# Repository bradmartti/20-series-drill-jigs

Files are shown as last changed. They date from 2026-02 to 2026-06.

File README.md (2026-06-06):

[][cc-by-nc-sa]

This work is licensed under a  
[Creative Commons Attribution-NonCommercial-ShareAlike 4.0 International License][cc-by-nc-sa].

[][cc-by-nc-sa]

[cc-by-nc-sa]: http://creativecommons.org/licenses/by-nc-sa/4.0/
[cc-by-nc-sa-image]: https://licensebuttons.net/l/by-nc-sa/4.0/88x31.png
[cc-by-nc-sa-shield]: https://img.shields.io/badge/License-CC%20BY--NC--SA%204.0-lightgrey.svg

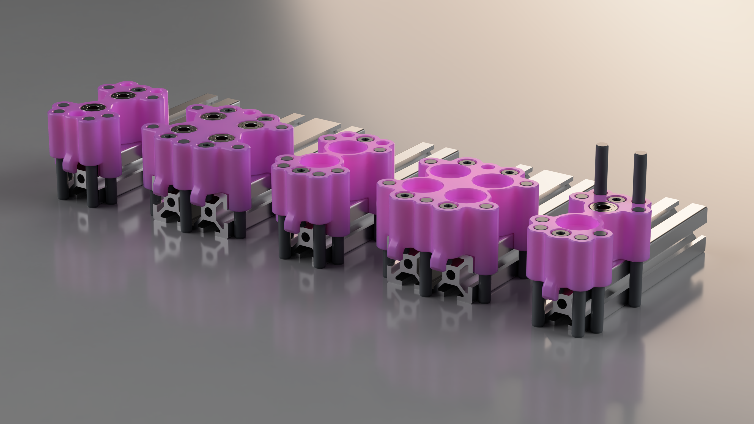
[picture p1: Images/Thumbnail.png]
Thumbnail


## Introduction

These jigs enable precise drilling of 20-series aluminum extrusions for through-hole counterbored joints and access-hole blind joints.

### Features
- Double bearing guides with tight tolerances provide excellent drill bit support for precise, clean holes
- Multi-point T-nut clamping for secure fixture connection
- T-nut anti-spin design prevents T-nuts from rotating, enabling quick and easy installation
- Optional side alignment pins for improved alignment and jig longevity
- End alignment pins for common fixed-offset drilling
- Convenient alignment locations for matching to measured marks on the extrusion
- Designed for Additive Manufacturing (DfAM)
- Optional multi-purpose jig that handles various extrusion sizes and joint types — ideal for non-repetitive or mixed jobs where setup/removal time is acceptable in exchange for fewer dedicated tools

## Hardware

| Item | Recommended Source |
|---|---|
| 685ZZ 5×11×5 mm bearing | [Aliexpress](https://www.aliexpress.com/item/1005006224445582.html) |
| R1038ZZ 3/8" × 5/8" × 5/32" bearing | [Amazon.ca](https://www.amazon.ca/HiPicco-R1038ZZ-Bearings-Miniature-Shielded/dp/B0CH37GYYF?th=1), [Amazon.com](https://www.amazon.com/FOCMKEAS-R1038ZZ-Industrial-Mechanical-Equipment/dp/B0B6WRXGZR) |
| 5 mm × 40 mm pin (or custom length) | [Aliexpress](https://www.aliexpress.com/item/4000473863693.html)|
| 5 mm drill bit | [Aliexpress - XUHAN](https://www.aliexpress.com/item/1005002617939096.html) |
| 5.5–9.5 mm step drill | [Aliexpress - DrillForce](https://www.aliexpress.com/item/32914005099.html#nav-specification) |
| 5 mm and 9.5 mm depth stop collars | [Aliexpress](https://www.aliexpress.com/item/1005005826023888.html) |
| M4 T-nut (9.5 mm length) | [Aliexpress](https://www.aliexpress.com/item/1005007883028035.html) |
| M4 × 20 mm SHCS screw | [Aliexpress](https://www.aliexpress.com/item/1005004527586307.html) |

## Important Notes
- Check the CAD files for exact quantities required per jig variant.
- Drill bits have very tight clearance with the bearings — lubricant is highly recommended for smooth motion and better cutting performance.
- **Use higher spindle RPM with a slower/controlled feed rate** to achieve a lower chip load — this prevents drill bit binding, and produces cleaner holes (apply very light pressure when hand-feeding).
- Pin holes should be drilled/reamed to 5 mm; apply light grease or lubricant so pins slide easily but do not fall out.
- Side alignment pins are optional for most variants (required for the multi-jig version); front/end alignment pins provide a fixed offset.
- Counterbore overhangs are intentionally bridged to simplify printing — insert bearings first, then drill out.
- If printed tolerances do not match your needs (e.g., too tight/loose), adjust them using the included Fusion 360 parameter file — use care for other changes, as major modifications may break the model.
- If bearings don't stay in place, adjust tolerances in CAD and/or use retaining compound to secure them.
- The 9.5 mm T-nut length is required for the anti-spin feature to function correctly (length can be adjusted in the CAD if needed).
- **When drilling 4040 extrusions for through-hole counterbored joints, pre-drill with the blind-hole jig to make the counterbore drilling easier and to account for the counterbore bit not reaching the full depth of the extrusion.**

<div style="display: flex; gap: 1%; justify-content: space-around;">
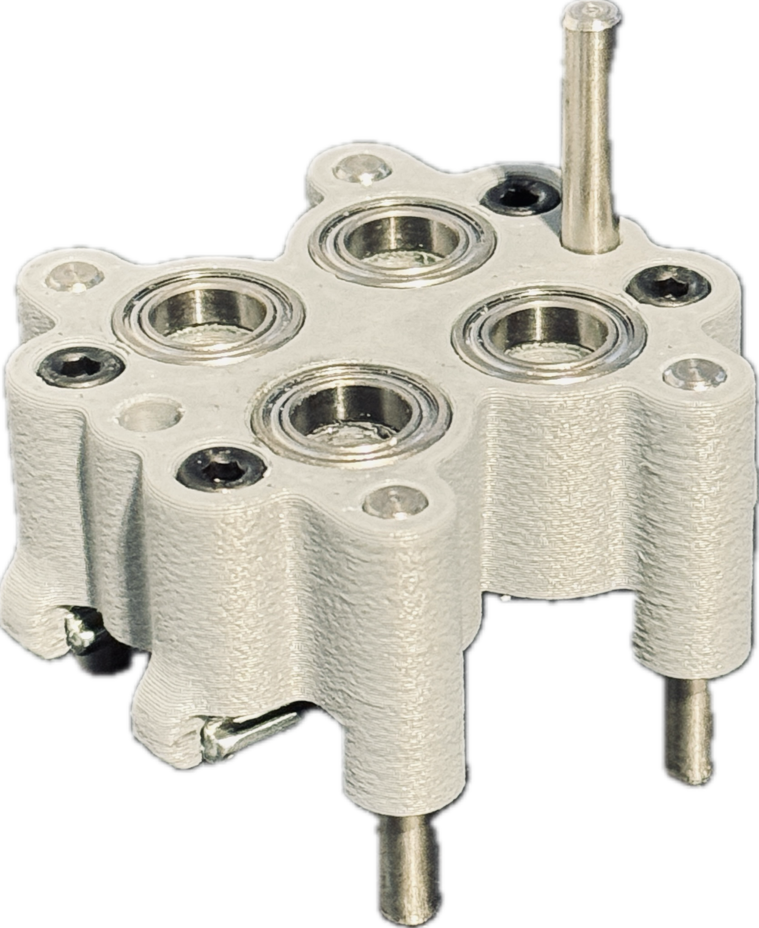
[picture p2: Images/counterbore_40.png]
  
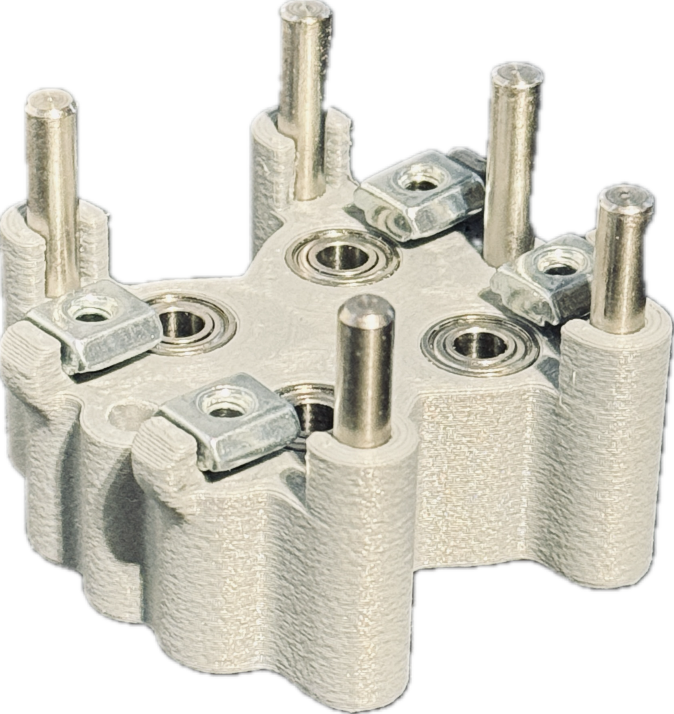
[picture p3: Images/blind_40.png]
  
</div>

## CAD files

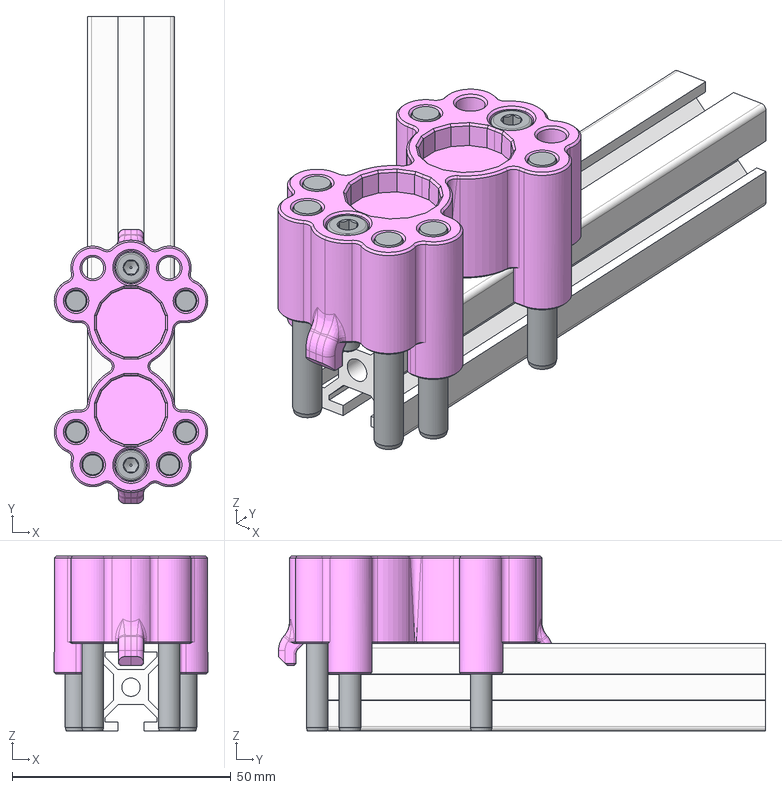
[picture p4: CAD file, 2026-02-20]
CAD/STEP/Counterbore_20.step
35.1 x 111.4 x 40.0 mm

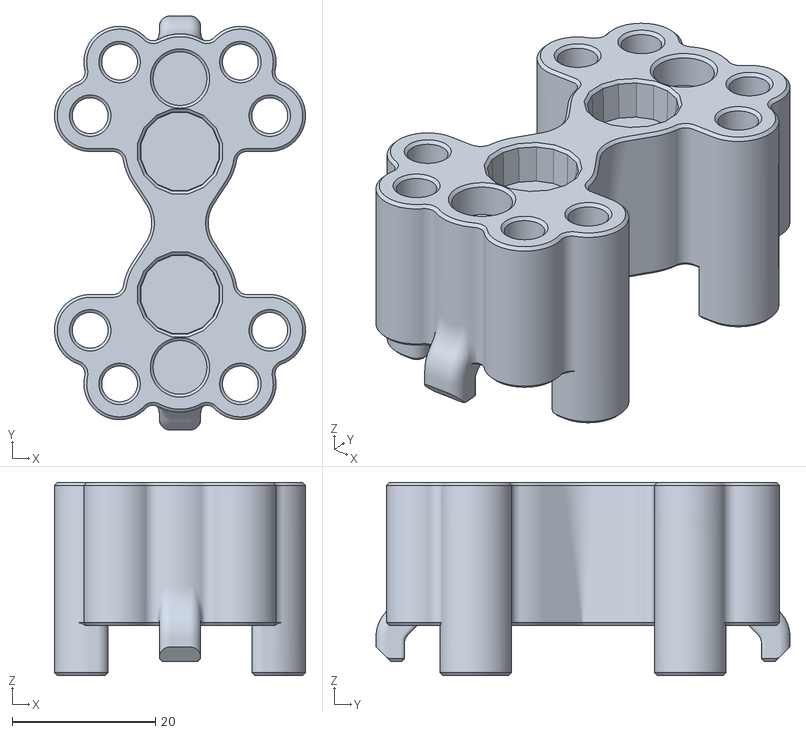
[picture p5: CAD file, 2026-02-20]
files_for_printing/Blind_20.stl
35.1 x 57.9 x 27.0

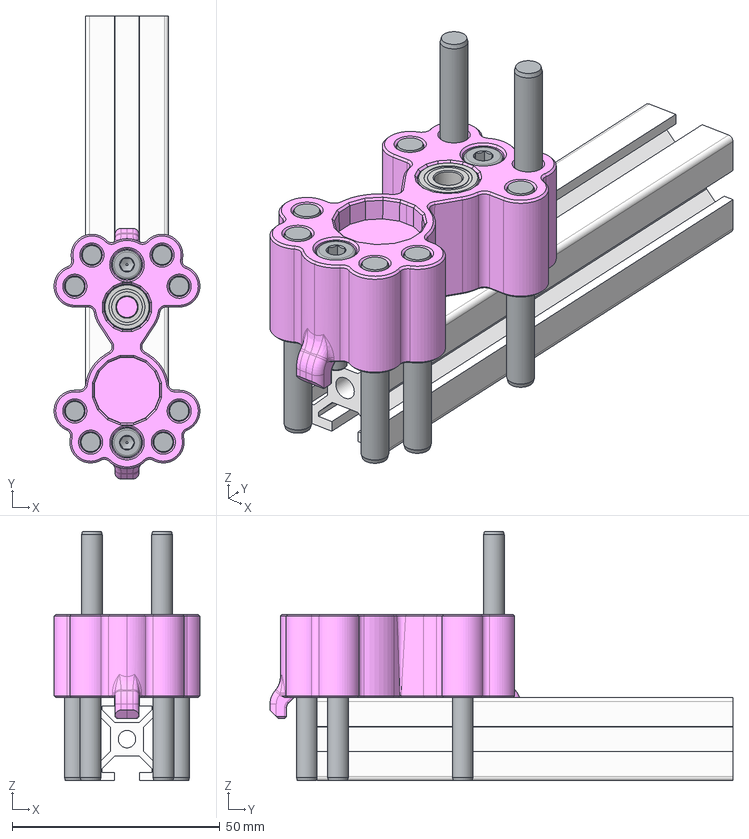
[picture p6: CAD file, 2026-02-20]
CAD/STEP/Multi_20.step
35.1 x 111.4 x 60.0 mm

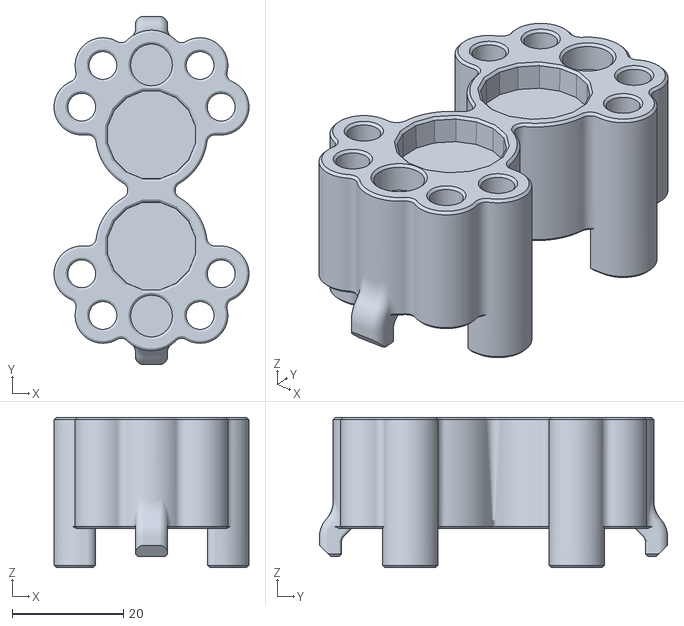
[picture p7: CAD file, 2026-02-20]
files_for_printing/Counterbore_20.stl
35.1 x 62.7 x 27.0

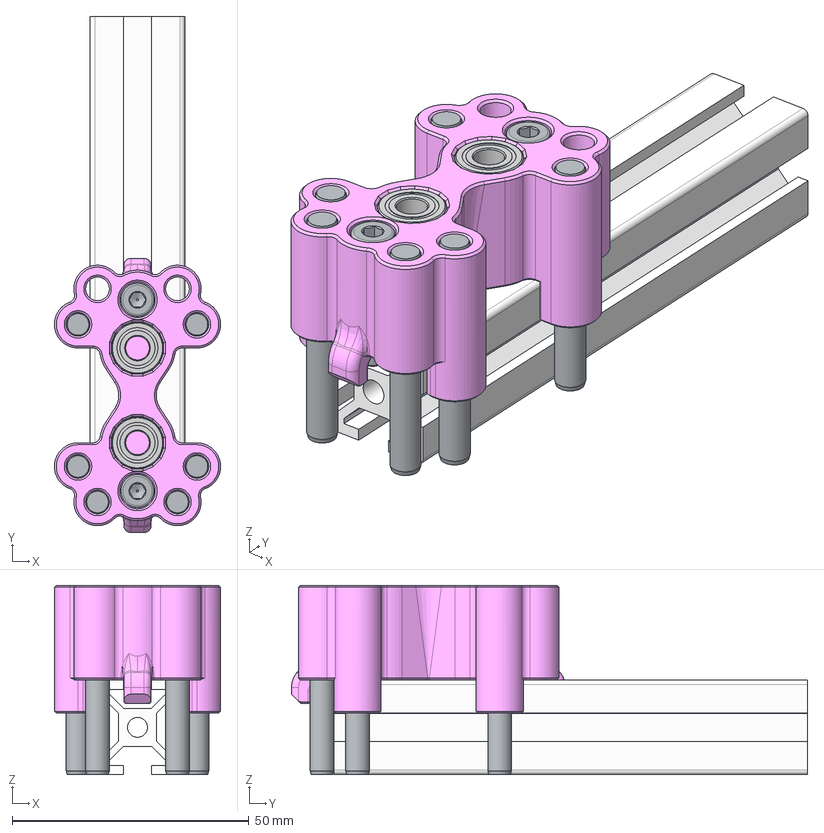
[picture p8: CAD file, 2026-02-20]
CAD/STEP/Blind_20.step
35.1 x 108.9 x 40.0 mm

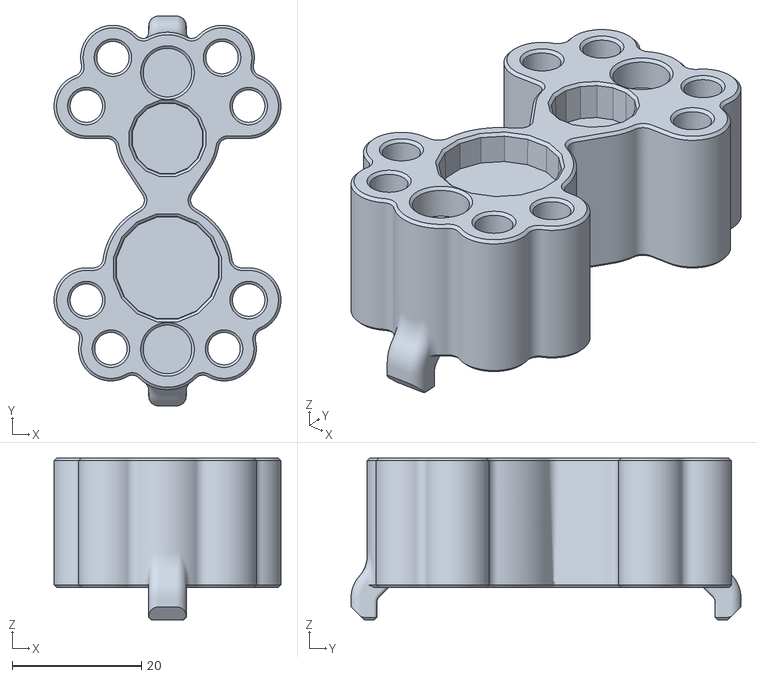
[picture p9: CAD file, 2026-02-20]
files_for_printing/Multi_20.stl
35.1 x 60.3 x 25.0

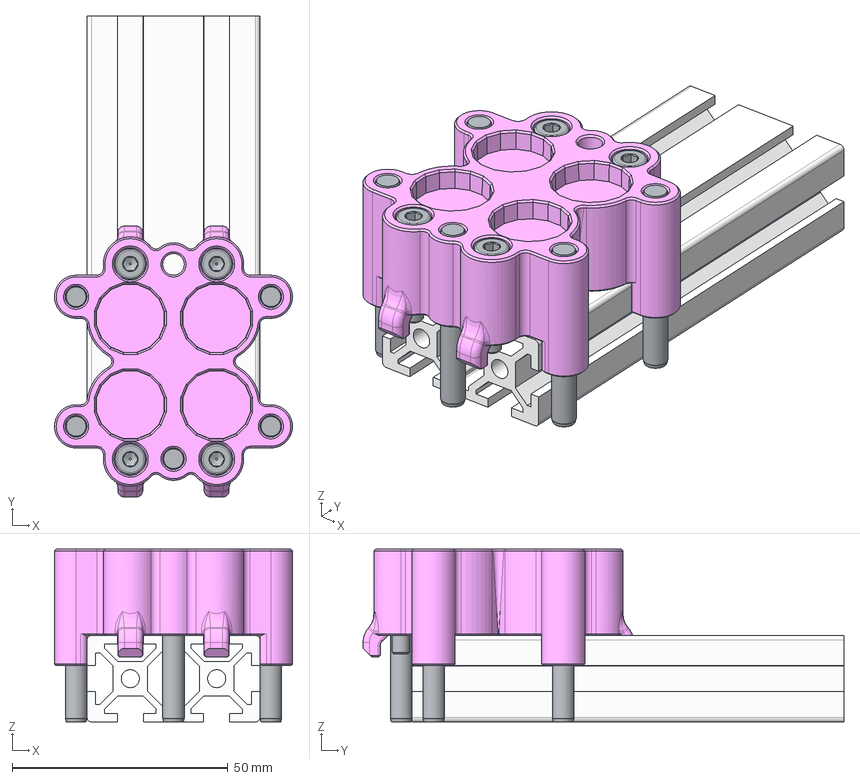
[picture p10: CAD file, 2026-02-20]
CAD/STEP/Counterbore_40.step
55.1 x 111.4 x 40.0 mm

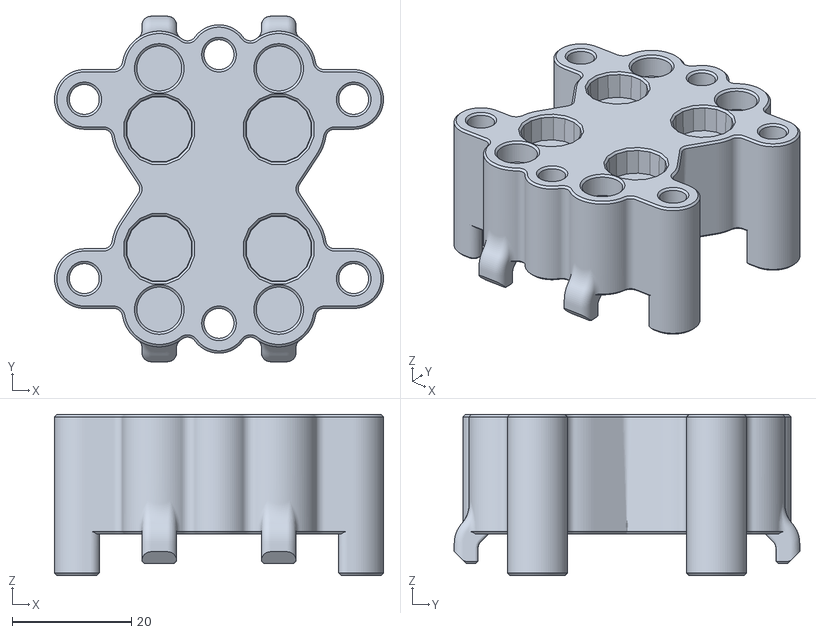
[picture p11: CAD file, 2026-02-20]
files_for_printing/Blind_40.stl
55.1 x 57.9 x 27.0

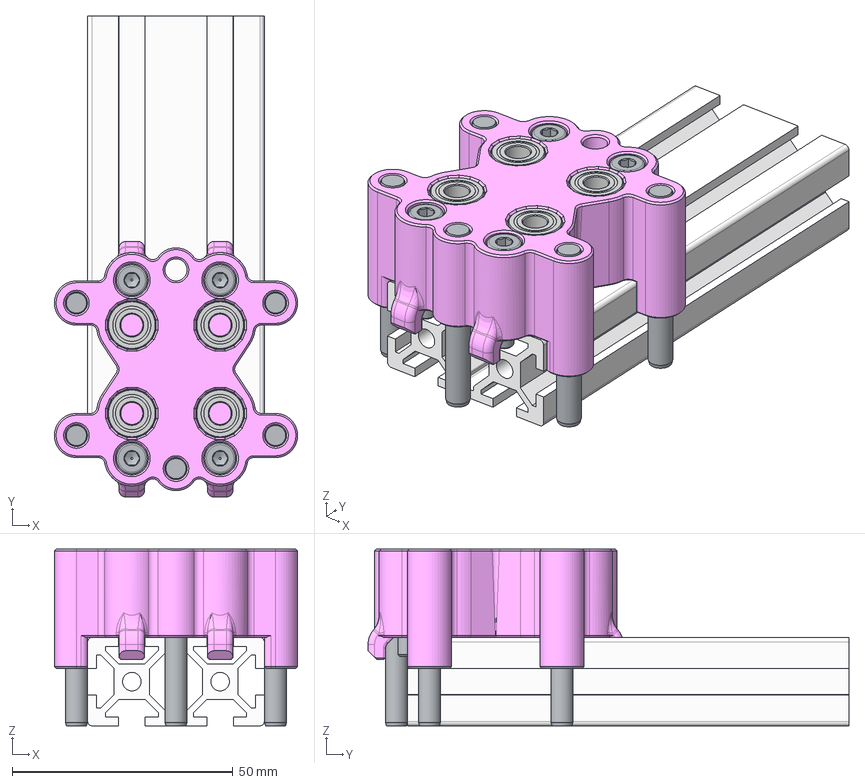
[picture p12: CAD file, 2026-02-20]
CAD/STEP/Blind_40.step
55.1 x 108.9 x 40.0 mm

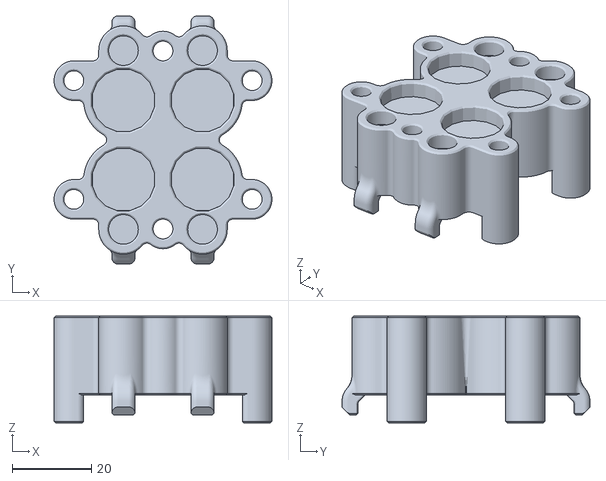
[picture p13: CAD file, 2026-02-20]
files_for_printing/Counterbore_40.stl
55.1 x 62.7 x 27.0

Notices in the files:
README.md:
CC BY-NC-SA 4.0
